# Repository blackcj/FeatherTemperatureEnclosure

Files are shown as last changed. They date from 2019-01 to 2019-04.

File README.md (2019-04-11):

# Feather Project Enclosure

**This project is a work in progress.**

Enclosure built for use with the [Particle mesh](https://www.particle.io/mesh/) product line. This line of micro controllers is built with the [feather specification](https://learn.adafruit.com/adafruit-feather/feather-specification).

## Parts

- [Particle mesh](https://www.particle.io/mesh/) product
- [Lithium Ion Cylindrical Battery](https://www.adafruit.com/product/1781)
- Temperature Sensor TBD

## Features

- Air vents for airflow
- Battery backup support
- Ability to press reset buttons without opening the enclosure
- Screw mounts

## Interior Support

### v0.1

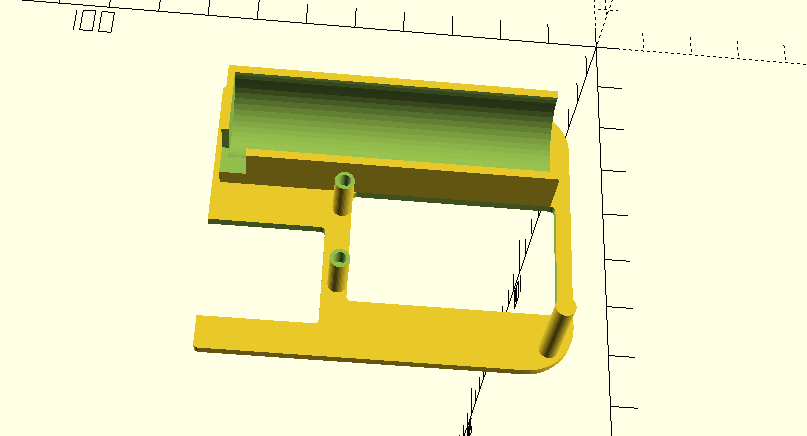
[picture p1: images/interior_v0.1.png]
Interior v0.1


Added interior support to keep battery and Photon core in place.

## Enclosure

### v0.4

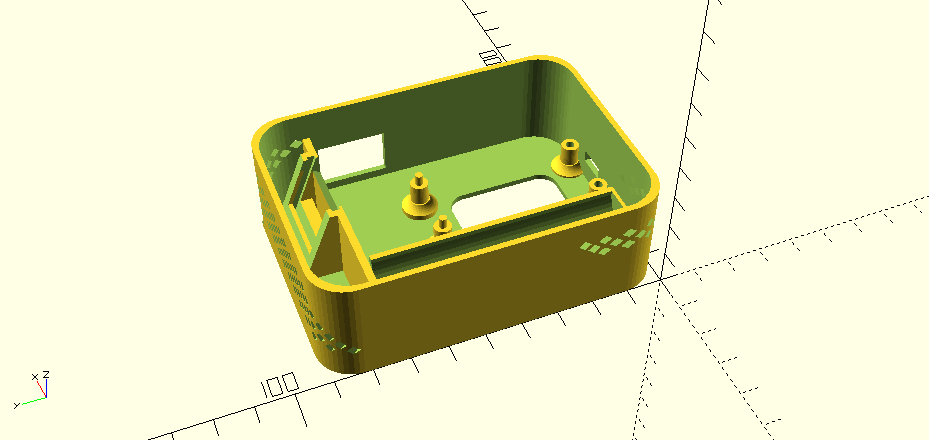
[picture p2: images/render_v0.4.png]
Render v0.4


Added a slot for a small sensor to fit into. Expanded the size to accomodate the space for the sensor and power switch.

**Settings**

Same as v0.1

### v0.3

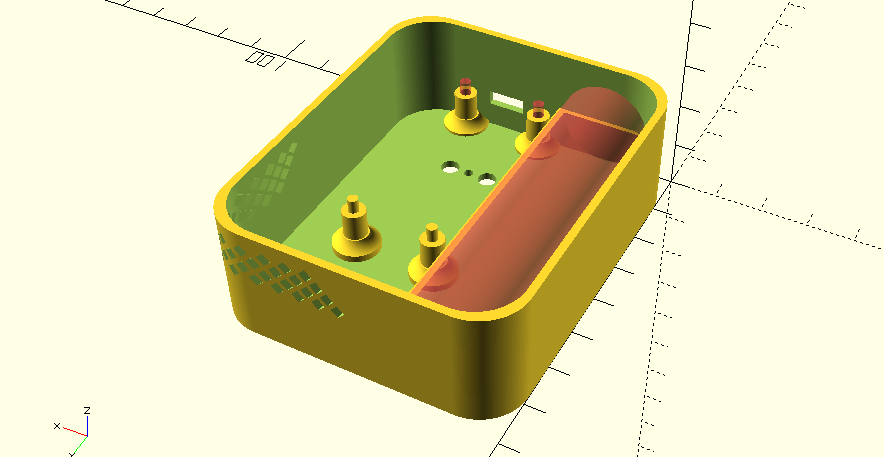
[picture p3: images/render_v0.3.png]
Render v0.3


Switching the design to a rectangle with rounded corners is a much better utilization of the space. The next step will be designing a place for the sensors to be mounted. The sensors will need some distance from the micro controller to avoid throwing off the temperature values.

**Settings**

Same as v0.1

**Time to print**

- Print time base: 2 hours 18 minutes

### v0.2

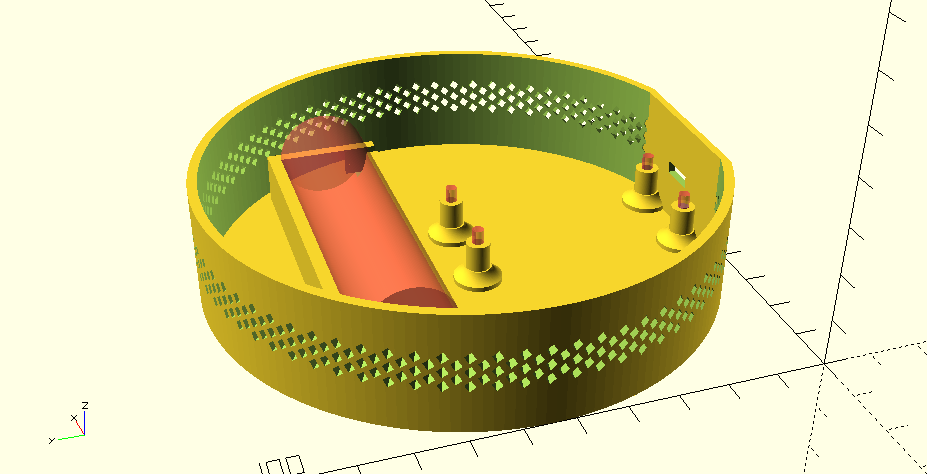
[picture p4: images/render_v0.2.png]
Render v0.2


After adding the battery holder and feather board mounts, it's clear the circular enclosure is going to be too big. The next version will be a rounded rectangle to maximize space. Both the battery holder and screw mounts were the correct size but the micro usb opening was in the wrong position. This will be corrected in the next version.

**Settings**

Same as v0.1

**Time to print**

I stopped the print half way through so the total time is unknown.

### v0.1

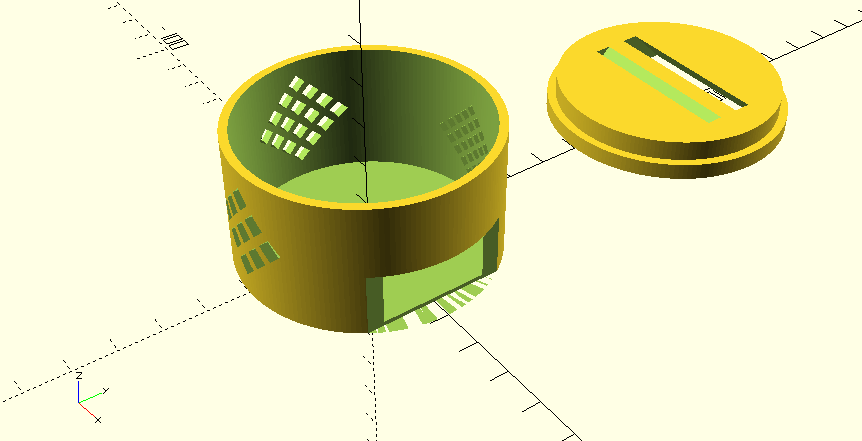
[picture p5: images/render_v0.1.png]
Render v0.1


This was a proof of concept to test venting and wall thickness. It turned out well but was too small (as expected). All vents looked good and printed without support. The lid fit snuggly around the base.

**Settings**

- Wall thickness: 1.2mm
- Layer height: 0.2mm
- Printing temperature: 215 C
- Print speed: 60 mm / s
- Brim speed: 10 mm / s
- Top / bottom speed: 20 mm / s
- Inland PLA+ - Black

**Time to print**

- Print time base: 2 hours 19 minutes
- Print time lid: 1 hour 48 minutes

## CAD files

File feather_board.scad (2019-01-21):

$fn = 64; // curved resolution (used for cylinders and spheres)

rotate(180,[0,1,0]) featherBoard();

// Featherboard with usb
module featherBoard() {
    difference() {
        // PCB
        rcube([22.86,50.8,1.19], 2.5);
        // Holes for mounting
        translate([2.54,2.54,-2])cylinder(r=1.4, h=14);;
        translate([2.54,48.26,-2])cylinder(r=1.4, h=14);;
        translate([20.32,48.26,-2])cylinder(r=1.4, h=14);;
        translate([20.32,2.54,-2])cylinder(r=1.4, h=14);;
    }
    // Micro USB
    translate([7.43,-1.2,-2.6]) {
        cube([8, 5, 2.7]);
    }
    // Buttons
    translate([15.33,17.42,-2])cylinder(r=1.5, h=2);
    translate([6.7,17.42,-2])cylinder(r=1.5, h=2);
}

// Rounded rectangle
module rcube(size, radius) {
    // rcube module found here: https://www.prusaprinters.org/parametric-design-in-openscad/
    hull() {
        translate([radius, radius]) cylinder(r = radius, h = size[2]);
        translate([size[0] - radius, radius]) cylinder(r = radius, h = size[2]);
        translate([size[0] - radius, size[1] - radius]) cylinder(r = radius, h = size[2]);
        translate([radius, size[1] - radius]) cylinder(r = radius, h = size[2]);
        //translate([1, size[1] - 1]) cylinder(r = 1, h = size[2]);
    }
}

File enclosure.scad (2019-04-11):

// Global config variables
enclosure_height = 30;
enclosure_length = 92;
enclosure_width = 66;
enclosure_radius = 40;
wall_thickness = 1.6;
$fn = 48; // curved resolution (used for cylinders and spheres)

//bottomLayer();
interiorSupport();

// Position all of the modules
module bottomLayer() {
    difference() {
        buildBase();
        // Micro usb slot
        translate([34.9,-1,7.1])cube([8.2,4,3.5]);
        // Hole on the bottom of the enclosure
        translate([30,10,-1])rcube([18,32,10], 5);
        // Opening for power switch
        translate([enclosure_width - wall_thickness - 1,enclosure_length - 38,4]) {
            cube([5,19,13]);
        }
    }

    difference() {
        translate([30,4.1,0]) {
            featherScrew(1.1);
        }
        translate([20,-1.1,-1]) {
            cube([41,wall_thickness+1,enclosure_height + 2]);
        }
    }

    translate([27,wall_thickness +0.5,0]) {
        rotate(90, [0,0,1]) {
            batteryHolderBottom();
        }
    }
}

translate([27.6,wall_thickness,10]) {
    //featherBoard();
}

module batteryHolderBottom() {
    difference() {
        translate([0,1,1]) {
            cube([73.46, 22, 11]);
        }
        translate([1,12,12]) {
            rotate(90, [0,0,1]) {
                rotate(90, [1,0,0]) {
                    #cylinder(r=9.35, h=71);
                }
            }
        }
        translate([69.5,-1,6]) {
            cube([2.5,8,8]);
        }
        translate([2,-1,6]) {
            //cube([2.5,8,6]);
        }
    }
}

module rcube2(size, radius) {
    // rcube module found here: https://www.prusaprinters.org/parametric-design-in-openscad/
    hull() {
        translate([radius, radius]) cylinder(r = radius, h = size[2]);
        translate([size[0] - radius, radius]) cylinder(r = radius, h = size[2]);
        translate([size[0] - 1, size[1] - 1]) cylinder(r = 1, h = size[2]);
        translate([1, size[1] - 1]) cylinder(r = 1, h = size[2]);
        //translate([1, size[1] - 1]) cylinder(r = 1, h = size[2]);
    }
}

module rcube(size, radius) {
    // rcube module found here: https://www.prusaprinters.org/parametric-design-in-openscad/
    hull() {
        translate([radius, radius]) cylinder(r = radius, h = size[2]);
        translate([size[0] - radius, radius]) cylinder(r = radius, h = size[2]);
        translate([size[0] - radius, size[1] - radius]) cylinder(r = radius, h = size[2]);
        translate([radius, size[1] - radius]) cylinder(r = radius, h = size[2]);
        //translate([1, size[1] - 1]) cylinder(r = 1, h = size[2]);
    }
}

// Base of enclosure
module buildBase() {
    translate([0, enclosure_length,0]) {
        
        platform();
    }
    
    // Cylinder with a smaller cylinder cut out of it
    difference() {

        outerWall();
        // Flat back for power hookup
        translate([enclosure_radius - 5,-10,5]) {
          //cube([8,20,7]);
        }
        translate([enclosure_width / 2,enclosure_length / 2,enclosure_height - 16]) {
          radialVents(2, 6, 2, 2, enclosure_radius + 20, 22, 28);
        }
        translate([enclosure_width / 2,enclosure_length / 2,enclosure_height - 25]) {
          radialVents(2, 6, 2, 6, enclosure_radius + 20, 116, 127);
        }
    }
}

module outerWall() {
     difference() {
        rcube([enclosure_width,enclosure_length,enclosure_height], 10);

        //cylinder(h = enclosure_height, r = enclosure_radius);
        // Make the cylinder hollow
        translate([wall_thickness,wall_thickness,wall_thickness]) {
            rcube([enclosure_width - wall_thickness * 2, enclosure_length - wall_thickness * 2,enclosure_height], 10);
          inner_height = enclosure_height;
          inner_radius = enclosure_radius - (wall_thickness * 2);
          //cylinder(h = inner_height, r = inner_radius, center = false);
        }
    }
    
}

module platform() {
    holder_start = enclosure_width / 2;
    translate([0,-14,0]) {
        difference() {
            holder();
            translate([holder_start,0,0]) {
                translate([2,5,4]) {
                    #rotate(22, [1,0,0])cube([22,2,24]);
                }
                translate([3,-5,enclosure_height - 14]) {
                    rotate(22, [1,0,0])cube([20,10,6]);
                }
                translate([-1,10,0]) {
                    rotate(22, [1,0,0])cube([28,10,enclosure_height]);
                }
            }
        }
        
    }
}

module holder() {
    holder_start = enclosure_width / 2;
    translate([holder_start,0,0])cube([26,14,8]);
    translate([holder_start,-1,0])cube([3,8,enclosure_height - 8]);
    translate([holder_start + 23,-1,0])cube([3,8,enclosure_height - 8]);
    translate([1,-3,0])cube([enclosure_width - 2,2,enclosure_height - 8]);
} 

// Radial vents
// ventSpacing in mm
// horizontalSpacing in degrees (divisible by 360)
module radialVents(verticalSpacing, horizontalSpacing, size, numRows, ventRadius, startAngle, finishAngle) {
    for ( m = [0 : numRows] ){
        for ( k = [startAngle : finishAngle] ){
            // Rotate by 45 degrees to avoid needing support when printing
            translate([0,0,m * verticalSpacing + 4]) {
                offset = horizontalSpacing / 2;
                rotate( k * horizontalSpacing - m * offset, [0, 0, 1]){
                    rotate( 45, [0, 1, 0]) {
                        cube([size, ventRadius, size]);
                    }
                }
            }
        }
    }
}

// Featherboard with usb
module featherBoard() {
    difference() {
        rcube([22.86,50.8,1.19], 2.5);
        translate([2.54,2.54,-2])cylinder(r=1.35, h=14);;
        translate([2.54,48.26,-2])cylinder(r=1.35, h=14);;
        translate([20.32,48.26,-2])cylinder(r=1.35, h=14);;
        translate([20.32,2.54,-2])cylinder(r=1.35, h=14);;
    }
    translate([7.43,-1.2,-2.6]) {
        cube([8, 5, 2.7]);
    }
    translate([15.33,17.42,-2])cylinder(r=1.5, h=2);
    translate([6.7,17.42,-2])cylinder(r=1.5, h=2);
}

module featherFriction(pegRadius) {
    translate([0,0,0])frictionmount(pegRadius);
    translate([0,45.72,0])frictionmount(pegRadius);
    translate([17.78,45.72,0])frictionmount(pegRadius);
    translate([17.78,0,0])frictionmount(pegRadius);
}

// Screw mount spaced for a feather board
module featherScrew(pegRadius) {
    translate([0,0,0])screwmountM25();
    translate([0,45.72,0])frictionmount(pegRadius);
    translate([17.78,45.72,0])frictionmount(pegRadius);
    translate([17.78,0,0])screwmountM25();
}

// M2.5 screw mount for 6mm length M2.5 screws
module screwmountM25() {
    translate([0,0,1.9]) {
        rotate_extrude(convexivity = 10) {
            translate([2.5,0,0]) {
                intersection() {
                    square(8);
                    difference() {
                        square(5, center = true);
                        translate([4,4])circle(4);
                    }
                }
            }
        }
    }
    cylinder(r=5, h=2);
    difference() {
        cylinder(r=2.5, h=10);
        translate([0,0,4]) {
            cylinder(r=1.2, h=9);
        }
    }
}

// Friction mount for screw holes
module frictionmount(pegRadius) {
 translate([0,0,2.8]) {
        rotate_extrude(convexivity = 10) {
            translate([2.5,0,0]) {
                intersection() {
                    square(8);
                    difference() {
                        square(5, center = true);
                        translate([4,4])circle(4);
                    }
                }
            }
        }
    }
    cylinder(r=5, h=3);
    cylinder(r=2.5, h=10);
    cylinder(r=pegRadius, h=14);
}

module interiorSupport() {
   difference() {
        translate([30,4.1,0]) {
            featherSupport();
        }
        translate([30,4.1,1.19]) {
            featherScrew(1.3);
        }
        translate([20,-1.1,-1]) {
            cube([41,wall_thickness+1,enclosure_height + 2]);
        }
    }
    translate([27,wall_thickness +0.5,0]) {
        rotate(90, [0,0,1]) {
            batteryHolderTop();
        }
    }
    difference() {
        translate([wall_thickness + 0.2,wall_thickness + 0.2,22]) {
            rcube2([enclosure_width - wall_thickness * 2 - 0.6, enclosure_length - wall_thickness * 2 - 13.5,2], 10);
          inner_height = enclosure_height;
          inner_radius = enclosure_radius - (wall_thickness * 2);
        }
        translate([26,5,-1])rcube2([25.5,42.8,30], 1);
        translate([35,53,-1])rcube([22,28,30], 1);
    }
    translate([enclosure_width - 7,7,3])cylinder(r=2, h=21);
}
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

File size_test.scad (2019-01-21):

$fn = 64; // curved resolution (used for cylinders and spheres)

// Add a ridge for increased stability
difference(){
    cube([100,60,6]);
    translate([1.5,1.5,1.4])cube([97,57,8]);
}

translate([6, 8, 0])featherFriction(1.35, 6);

translate([41.56, 8, 0])featherFriction(1.2, 12);

translate([77.12, 8, 0])featherFriction(1.1, 24);

module featherFriction(pegRadius, resolution) {
    translate([0,0,0])frictionmount(pegRadius, resolution);
    translate([0,45.72,0])frictionmount(pegRadius, resolution);
    translate([17.78,45.72,0])frictionmount(pegRadius, resolution);
    translate([17.78,0,0])frictionmount(pegRadius, resolution);
}

// Friction mount for screw holes
module frictionmount(pegRadius, resolution) { 
 translate([0,0,2.8]) {
        rotate_extrude(convexivity = 10) {
            translate([2.5,0,0]) {
                intersection() {
                    square(8);
                    difference() {
                        square(5, center = true);
                        translate([4,4])circle(4);
                    }
                }
            }
        }    
    }   
    cylinder(r=5, h=3);
    cylinder(r=2.5, h=12);
    cylinder(r=pegRadius, h=15, $fn = resolution);
}

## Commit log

2019-01-16 Added v0.1 enclosure code and notes.
    [enclosure.scad]
2019-01-17 Version 0.2 notes, code and image.
    [enclosure.scad]
2019-01-18 Version 0.3 notes, code and image.
    [enclosure.scad]
2019-01-19 Added separate file for the feather board. Using a plastic prototype makes it easier to test sizing without risking damaging the actual board.
    [feather_board.scad]
2019-01-19 Added file to use for testing friction fit mounts for the feather board.
    [size_test.scad]
2019-01-21 Minor modifications to dimensions of the board and mounts.
    [feather_board.scad, size_test.scad]
2019-02-20 Started on version 0.4. Moved the micro usb port up 0.2mm and added a platform for the sensor to slide into.
    [enclosure.scad]
2019-03-14 Version 0.4 notes, code and image.
    [enclosure.scad]
2019-04-11 Added interior support.
    [enclosure.scad]
2019-04-11 Updates to the interior support.
    [enclosure.scad]
